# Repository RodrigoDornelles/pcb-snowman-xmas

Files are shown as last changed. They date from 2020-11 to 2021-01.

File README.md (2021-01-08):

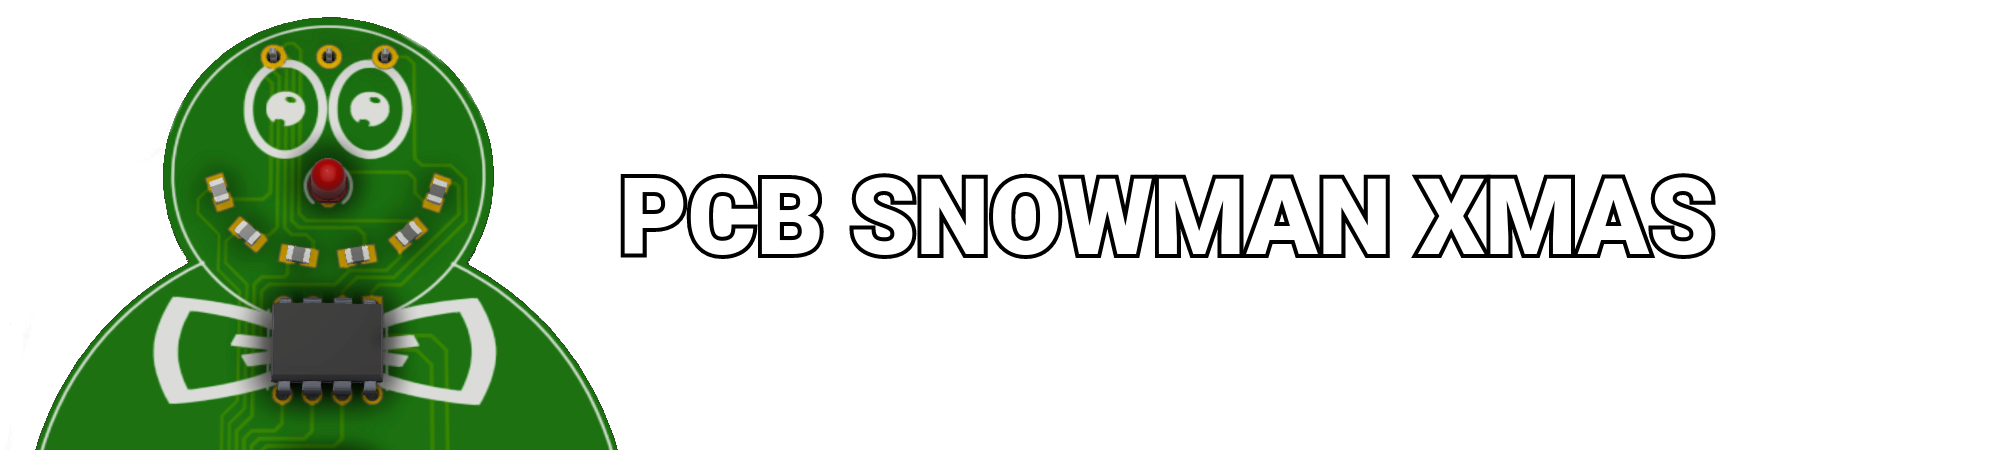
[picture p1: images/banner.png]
PCB Snowman Xmax








> printed circuit board artistic badge with xmas theme for [@Juliallabs](https://github.com/juliallabs) (JuliaLabs) competition (2020/NOVEMBER) promoved by [PCBWAY](https://pcbway.com)

## About ##
Musical snowman badge where all the electrical components are useful for decoration design, this PCB will play a complete Christmas music sound (melody and harmony) because of its 4 buzzers and it will also have a led pulse in a rhythmic way, as the hat rotates (knob pot) will increase the volume or turn off the badge.

* [click here to view all images](https://github.com/RodrigoDornelles/pcb-snowman-xmas/blob/master/IMAGES.md)

## Requirements ##
| Dependency | Platform | Description |
| :--- | --- | :--- |
| [RodrigoDornelles/arduino-tone-pitch](https://github.com/RodrigoDornelles/arduino-tone-pitch) | arduino lib | improve the pitch tune of piezos |
| [RodrigoDornelles/arduino-soft-buzzer](https://github.com/RodrigoDornelles/arduino-soft-buzzer) | arduino lib | allow multiple piezos to be played simultaneously |
| [SnapEDA CMT-8530S-SMT-TR](https://www.snapeda.com/parts/CMT-8530S-SMT-TR/CUI%20Devices/view-part/649163/) | eagle lib | fotoprint and symbol to **Eagle** project |
| [SnapEDA ATTINY85-20PU](https://www.snapeda.com/parts/ATTINY85-20PU/Microchip/view-part/?ref=search&t=attiny85) | autodesk 3d | fotoprint and symbol to **Eagle** project |
| [SnapEDA ATTINY85-20PU](https://www.snapeda.com/parts/ATTINY85-20PU/Microchip/view-part/?ref=search&t=attiny85) | autodesk 3d | added in the **Eagle** project for 3D view in the  **Fusion 360** |
| [GrabCad LED 3mm 2](https://grabcad.com/library/led-3mm-2) | autodesk 3d | added in the **Eagle** project for 3D view in the  **Fusion 360** |
| [GrabCad Potentiometer 3](https://grabcad.com/library/potentiometer-3) | autodesk 3d | added in the **Eagle** project for 3D view in the  **Fusion 360** |
| [CUI Devices CMT-8530S-SMT-TR](https://www.cuidevices.com/product/resource/3dmodel/cmt-8530s-smt-tr) | autodesk 3d | added in the **Eagle** project for 3D view in the  **Fusion 360** |

## First Draft ##
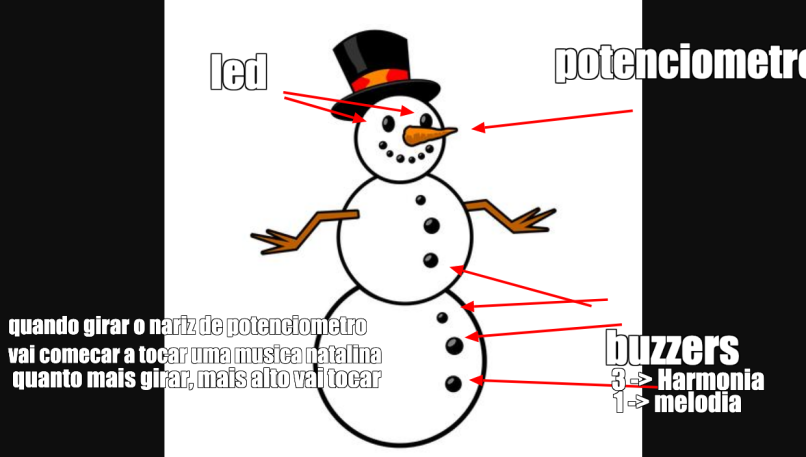
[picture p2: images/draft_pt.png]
draft1pt
|  |- 2x Led's<br/><br/>- 1x Potentiometer<br/><br/>- 3x Buzzer's for musical harmony<br/><br/>- 1x Buzzer for musical melody<br/><br/>_How work: when you turn your nose (potentiometer) you will start playing a Christmas song the more you turn the louder you will play._ |
| - | :- |

## Bill of Materials ##
| # | Designator | Qty | Part Number | Description |
| - | :--- | --- | :--- | :--- |
| 1 | R1 | 1 | WH148-1 10K L20 | RES POT 10.0K OHM 0.25W PTH |
| 2 | R2,R3,R4,R5,R6,R7 | 6 | RND1550805S8F2400T5E | RES 110.0 OHM 0.125W 1% 0815 SMD |
| 3 | LS1,LS2,LS3,LS4 | 4 | CMT-8530S-SMT-TR | 8.5 mm Magnetic Audio Transducer Passive Buzzer SMT  |
| 4 | U1 | 1 | ATTINY85-20PU | 8bit AVR Microcontroller Programmable Flash PTH |
| 5 | LED1 | 1 | L-424HDT | 2.25 V Red LED 3mm Cylindrical |
| 6 | ???| ? | | Battery Holder |
| 7 | D1,D2,D3,D4 | 4 | SMA-DO214AC | Diode SMD |

## Eletronic Circuit ##
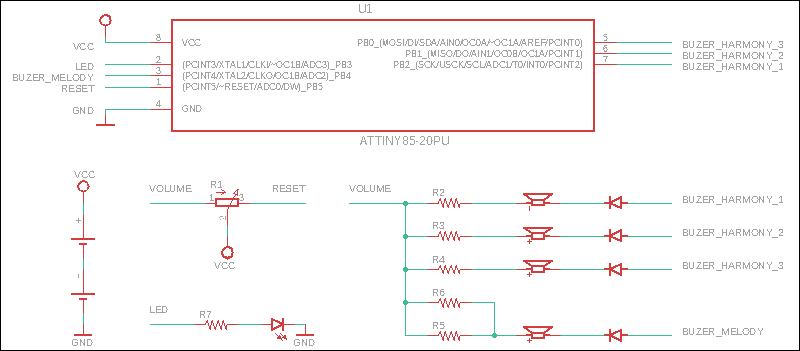
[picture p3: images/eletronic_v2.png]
eletric


## 3D View ##
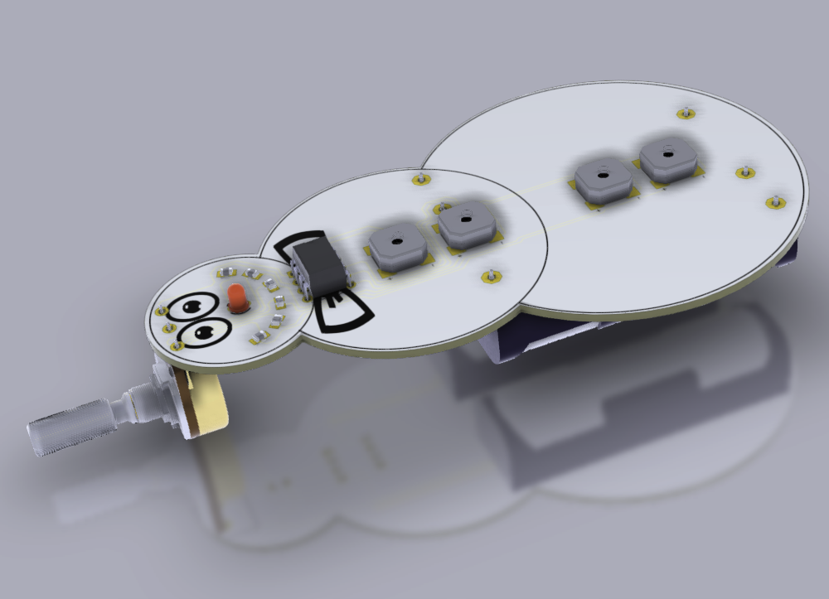
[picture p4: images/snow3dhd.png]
|  | 
| - |

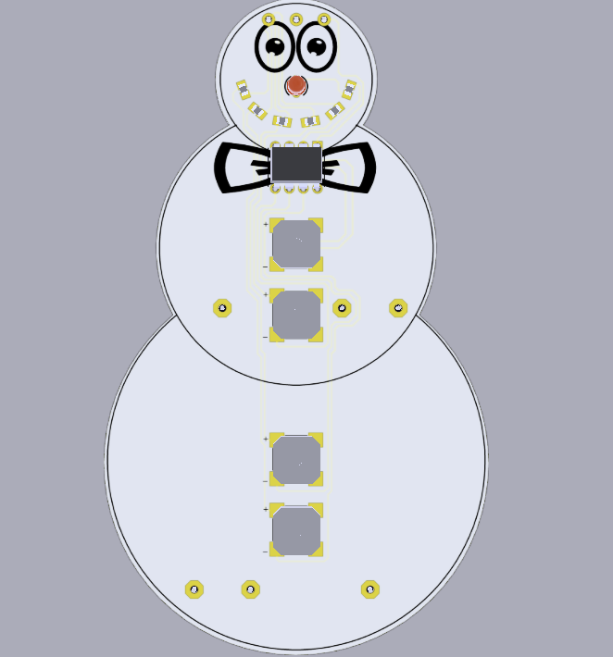
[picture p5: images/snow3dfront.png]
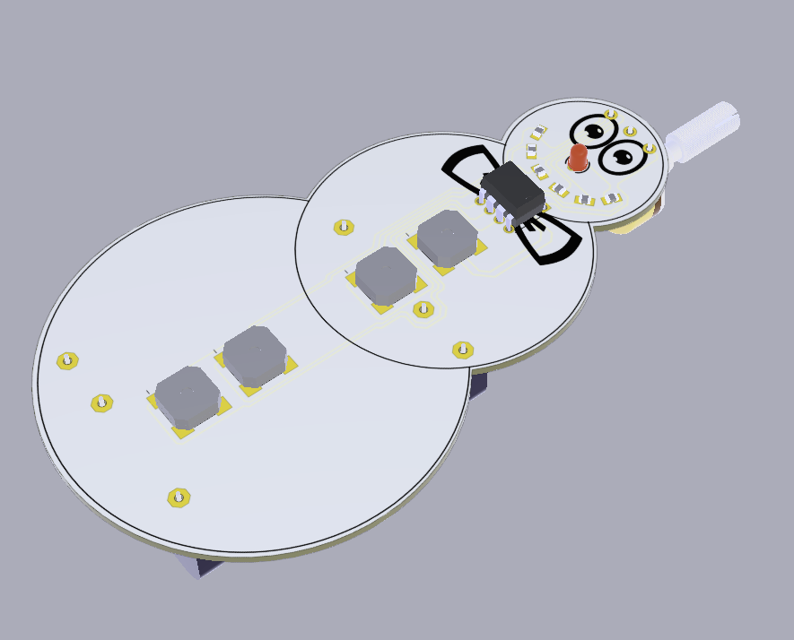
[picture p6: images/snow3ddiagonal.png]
|  | |
| - | - |

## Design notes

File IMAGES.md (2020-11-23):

|  |
| - |

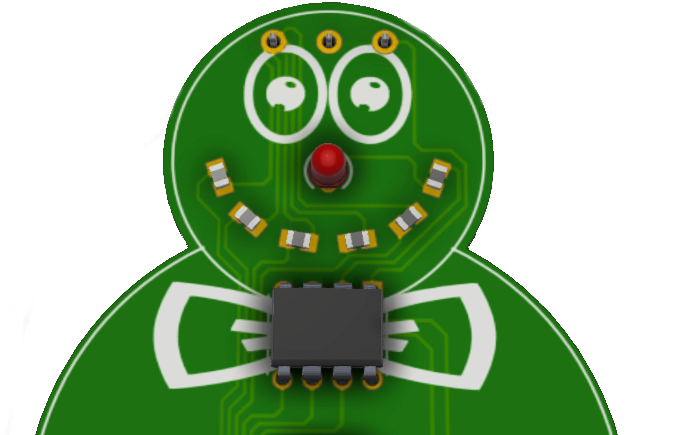
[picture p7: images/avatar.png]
|  |
| - |

|  |
| - |

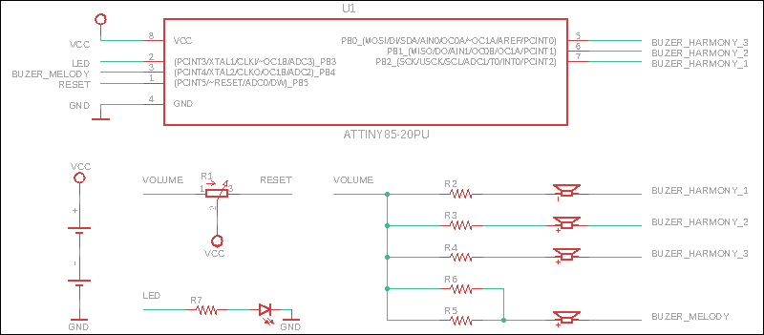
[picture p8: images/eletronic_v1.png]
|  |
| - |

|  |
| - |

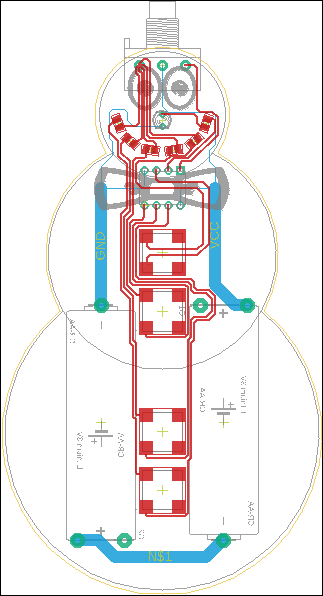
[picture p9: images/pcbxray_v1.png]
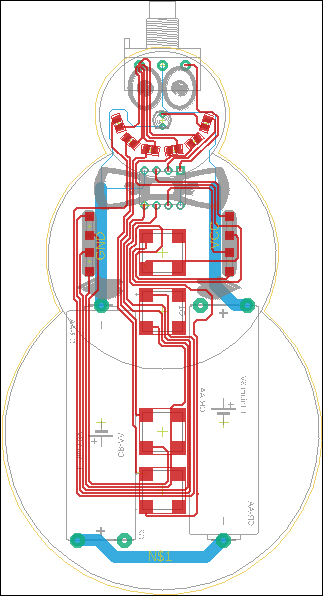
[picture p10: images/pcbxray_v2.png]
|  |  |
| - | - |

|  |  |
| - | - |

|  |
| - |

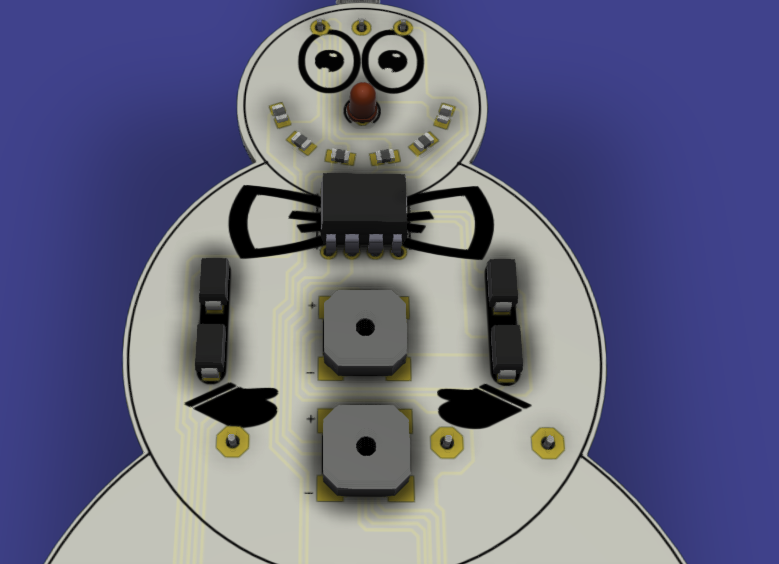
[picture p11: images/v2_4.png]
|  |
| - |

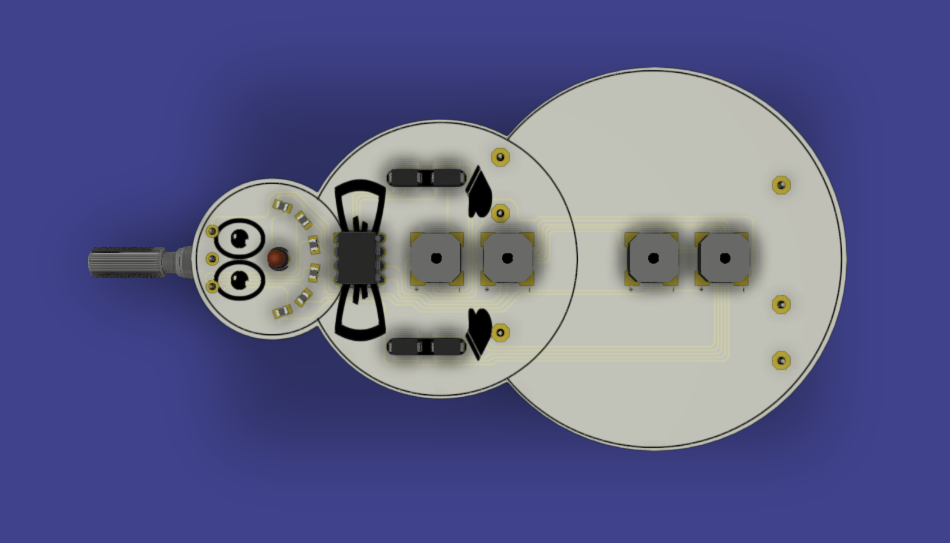
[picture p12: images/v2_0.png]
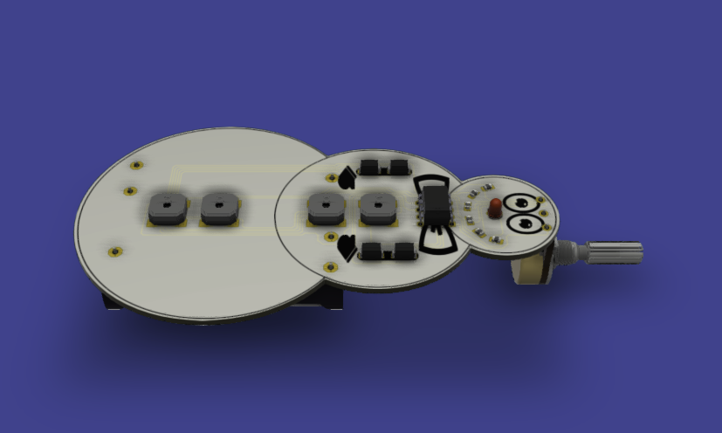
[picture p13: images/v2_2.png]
|  |  |
| - | - |

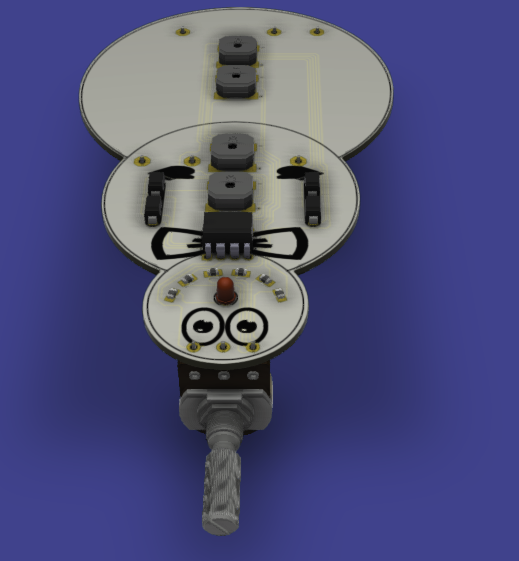
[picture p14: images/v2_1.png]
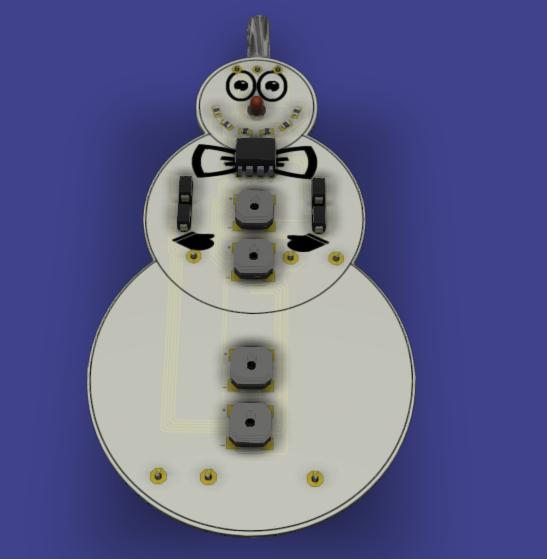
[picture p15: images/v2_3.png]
|  |   |
| - | - |

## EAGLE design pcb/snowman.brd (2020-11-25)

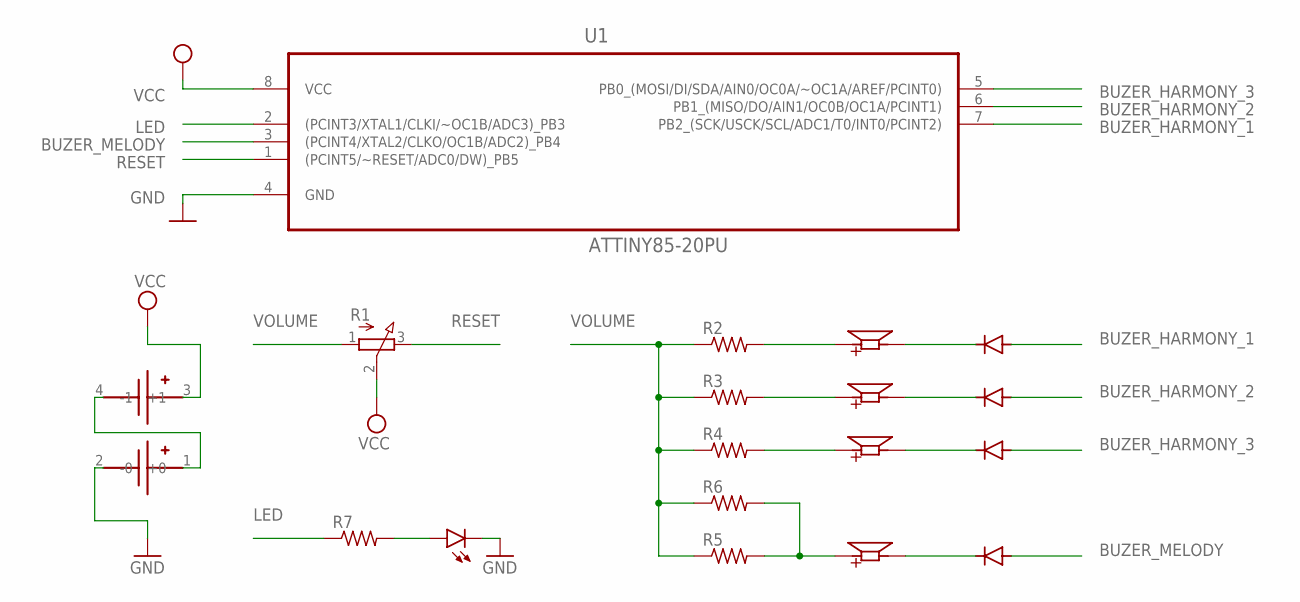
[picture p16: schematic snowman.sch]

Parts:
D1, D2, D3, D4: GF1; SMA-DO214AC
LED1: LED3MM
LS1, LS2, LS3, LS4: CMT-8530S-SMT; CUI_CMT-8530S-SMT
R1: 3RP/1610N
R2, R3, R4, R5, R6, R7: R-US_R0805; R0805
U1: ATTINY85-20PU; DIP254P762X533-8
U$1: BLOSSOM-BLM-18650-2PCS

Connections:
BUZER_HARMONY_1: D4.A, U1.7 (PB2_(SCK/USCK/SCL/ADC1/T0/INT0/PCINT2))
BUZER_HARMONY_2: D3.A, U1.6 (PB1_(MISO/DO/AIN1/OC0B/OC1A/PCINT1))
BUZER_HARMONY_3: D2.A, U1.5 (PB0_(MOSI/DI/SDA/AIN0/OC0A/~OC1A/AREF/P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)
BUZER_MELODY: D1.A, U1.3 ((PCINT4/XTAL2/CLKO/OC1B/ADC2)_PB4)
GND: LED1.K (C), U1.4 (GND), U$1.2 (-0)
LED: R7.1, U1.2 ((PCINT3/XTAL1/CLKI/~OC1B/ADC3)_PB3)
unnamed: LS4.P, R3.2
unnamed: LS2.P, R2.2
unnamed: LS3.P, R4.2
unnamed: LED1.A, R7.2
unnamed: LS1.P, R5.2, R6.2
unnamed: D4.K (C), LS2.N
unnamed: D3.K (C), LS4.N
unnamed: D2.K (C), LS3.N
unnamed: D1.K (C), LS1.N
unnamed: U$1.1 (+0), U$1.4 (-1)
RESET: R1.3 (E), U1.1 ((PCINT5/~RESET/ADC0/DW)_PB5)
VCC: R1.2 (S), U1.8 (VCC), U$1.3 (+1)
VOLUME: R1.1 (A), R2.1, R3.1, R4.1, R5.1, R6.1

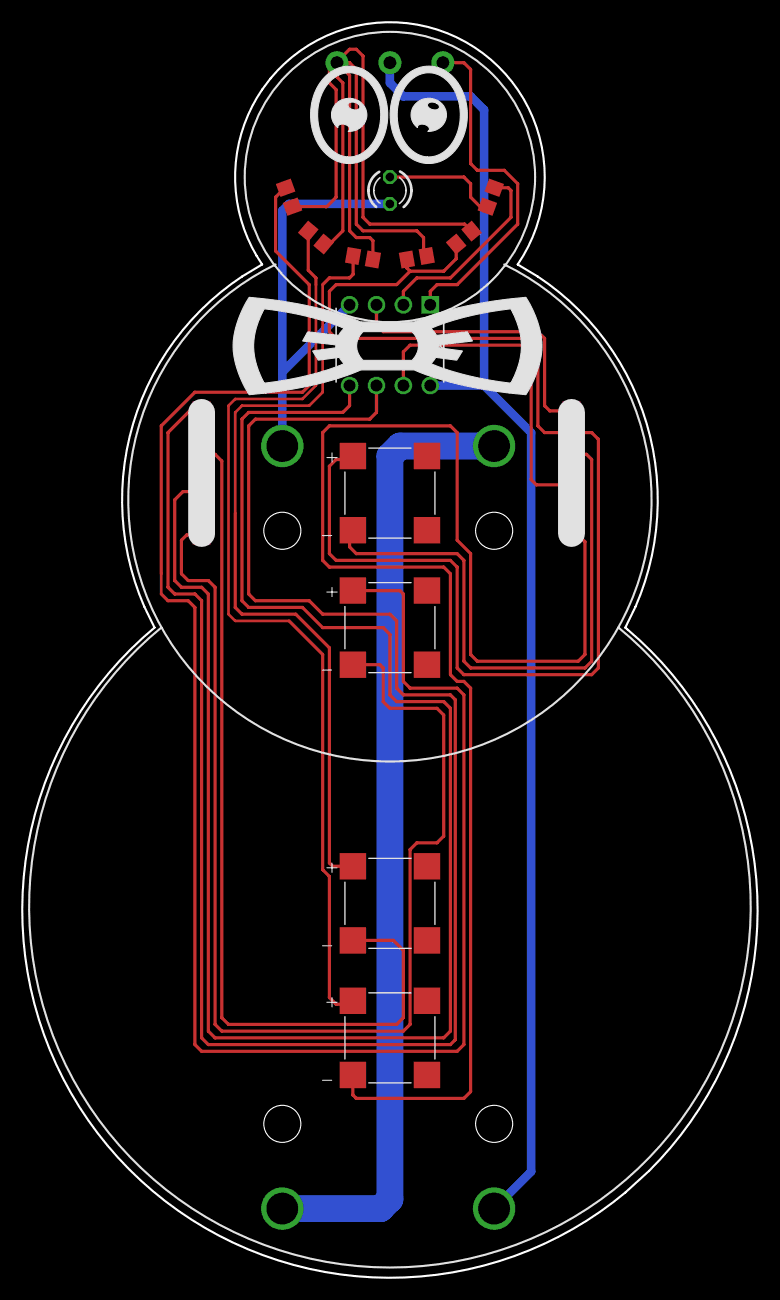
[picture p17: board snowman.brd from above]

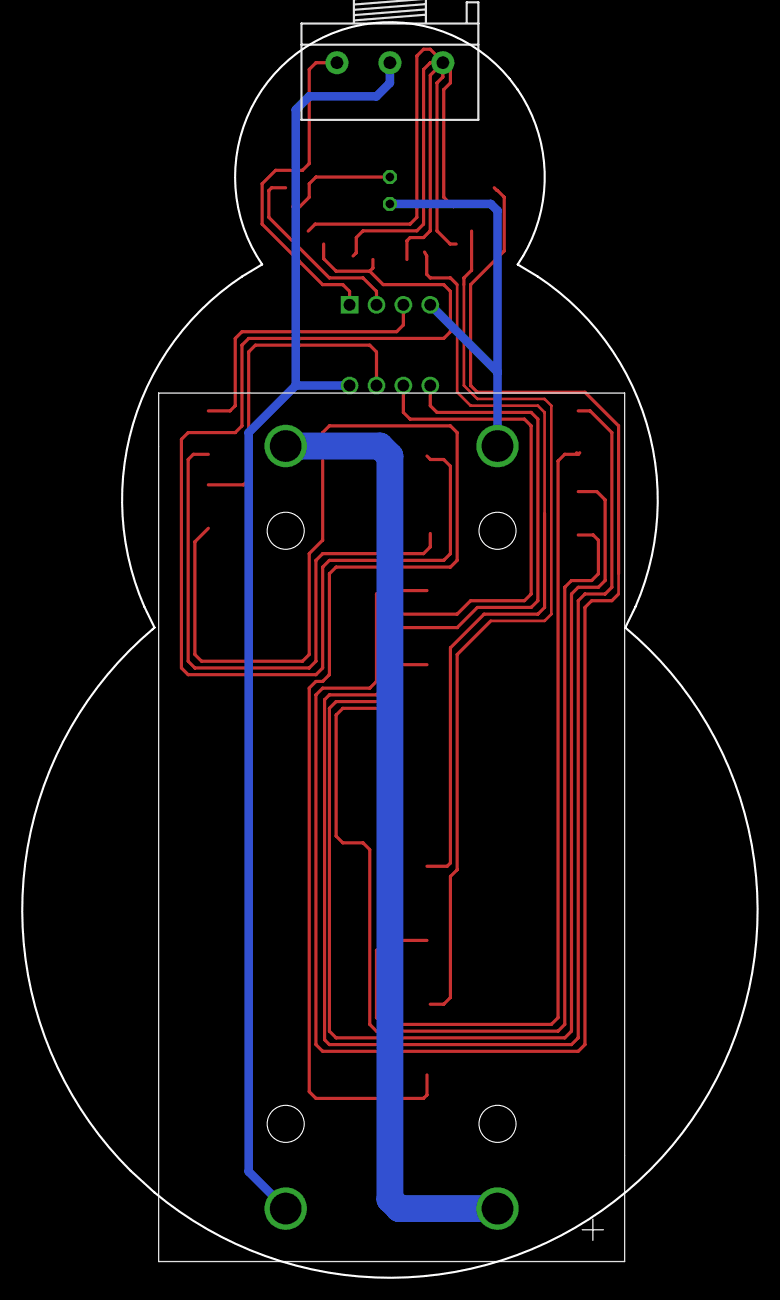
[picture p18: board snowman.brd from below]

Board: 2 copper layers, 69.4 x 118.5 mm, 18 parts (2 on the bottom side), 19 nets.

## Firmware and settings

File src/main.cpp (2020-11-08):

#include <Arduino.h>
#include <Reactduino.h>

#define NOTE_TIME 600

#define BUZZER_MELODY 6
#define BUZZER_HARMONY_1 7
#define BUZZER_HARMONY_2 8
#define BUZZER_HARMONY_3 9

#define MELODY_PLAY(await,note,temp);   \
  melody_delay += await;                \
  app.delay(melody_delay, []() {        \
                                        \
  });                                   \
  melody_delay += temp;                 

unsigned int melody_delay = 0;
unsigned int harmony_delay = 0; 

Reactduino app([] () {
  MELODY_PLAY(0, NOTE_D6, NOTE_TIME/1);
  MELODY_PLAY(0, NOTE_B7, NOTE_TIME/1);
  MELODY_PLAY(0, NOTE_A7, NOTE_TIME/1);
  MELODY_PLAY(0, NOTE_G7, NOTE_TIME/1);
});

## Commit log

2020-11-06 improve logical circuit
    [eletric.sch]
2020-11-06 draft board
    [eletric.brd]
2020-11-06 order components && init pcb trail
    [eletric.brd, eletric.sch]
2020-11-07 add power circuit
    [eletric.brd]
2020-11-07 pcb improve layout
    [eletric.brd, eletric.sch]
2020-11-07 pcb add art bowtie
    [eletric.brd]
2020-11-07 add pcb outline
    [eletric.brd]
2020-11-07 center piezos (clothing button)
    [eletric.brd]
2020-11-08 updates made in livestream
    [snowman.brd, snowman.sch]
2020-11-08 change eletronic circuit image
2020-11-08 add 3d
    [snowman.brd, snowman.sch]
2020-11-09 change pcb colors
    [snowman.brd]
2020-11-18 add Bill of Materials header to docs
2020-11-18 update bill of materials
2020-11-18 add PTH types in bill of materials
2020-11-20 add diode current filter to buzzers
    [snowman.sch]
2020-11-20 update copper trails
    [snowman.brd]
2020-11-20 adjust arms
    [snowman.brd]
2020-11-23 simplify bill of materials
2020-11-25 add resistor & potentiometer & led part numbers
2020-11-25 replace component CR-AA -> BLOSSOM-BLM-18650-2PCS
    [snowman.brd, snowman.sch]
2020-11-25 update bom list part numbers
